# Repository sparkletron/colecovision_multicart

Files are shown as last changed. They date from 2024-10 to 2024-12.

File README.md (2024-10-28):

# Colecovision Multicart
## 15 in 1 flash ROM cart for Colecovision 32KiB ROMS.



author: Jay Convertino  

date: 2024.10.26

license: MIT

## Release Versions
### Current

  - pre-alpha

### Past

  - none
  
## Requirements

  - KiCad v7.X
  - xc8 v2.31 or greater
  - sdcc v4.0.0 or greater
  - make (build-essential)

  Tested on Ubuntu 22.04

## Brief Information

  Be sure to pull ALL submodules. The command for this is...

  ```console
  git submodule update --init --recursive
  ```

  This project creates a complete 15 in 1 multicart for the Colecovision. It will generate the needed ROM
  image, and firmware. Provides all the files needed for PCB creation, and the 3D printed case creation.

  No valid Colecovision ROMs are included in this project. Only valid ROM is the multicart application
  generated by RODAC. Game ROMs in RODAC are random data written in various bank sizes for testing only.

  Each folder in this root directory contains a part of the project, they are as follows.
  - docs, all documentation and detailed user manual.
  - schematic, Electrical schematic and gerbers from KiCAD.
  - src, all source files used to build the Multicart launcher and PIC support chip firmware.
  - models, STL files for printing out cart shell.

## Detailed Information

  For detailed usage information, please navigate to one of the following sources. They are the same, just in a different format.

  - [colecovision_multicart.pdf](docs/manual/colecovision_multicart.pdf)
  - [github wiki](https://github.com/sparkletron/colecovision_multicart/wiki)

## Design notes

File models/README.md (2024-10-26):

# Colecovision Multicart STL directory

author: Jay Convertino  

date: 2024.10.26

license: MIT

## Requirements
  - STL 3D printer application, CURA, simplify, etc.

  Tested on with a ABS on a D6 printer.

## Tips
  - Print using ABS at 100.5% sizing for both (ABS shrinks, alter this for your brand if needed).

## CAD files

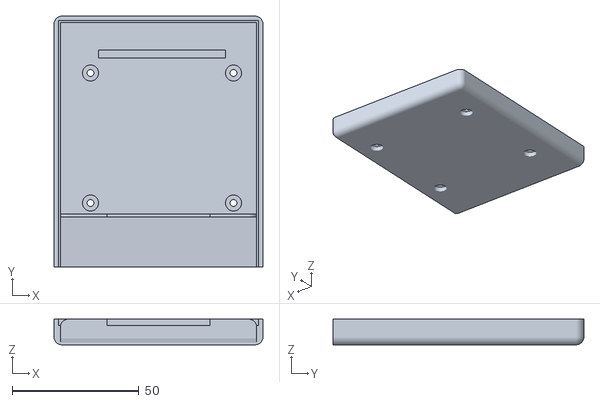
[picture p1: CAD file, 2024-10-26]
models/bottom.stl
82.6 x 99.1 x 10.2

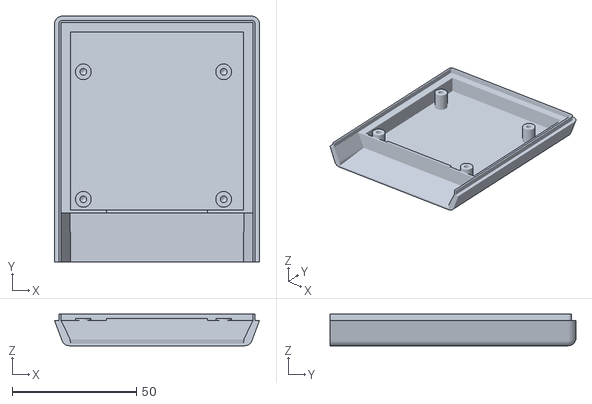
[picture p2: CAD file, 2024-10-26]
models/top.stl
82.6 x 99.1 x 12.7

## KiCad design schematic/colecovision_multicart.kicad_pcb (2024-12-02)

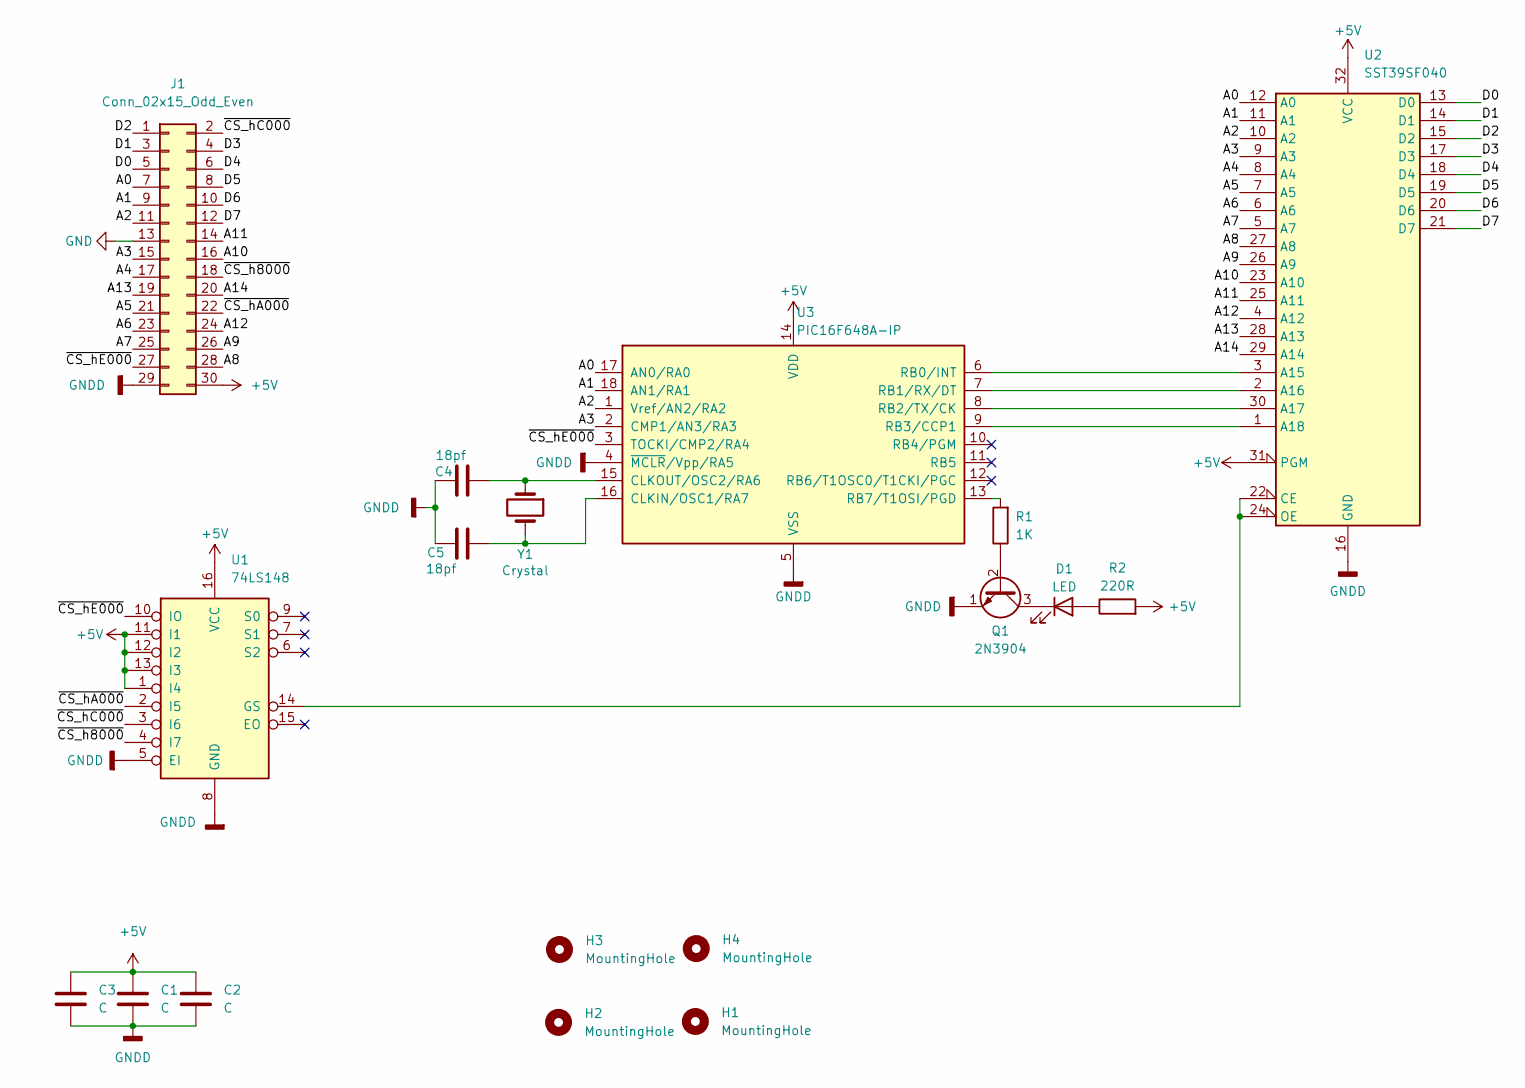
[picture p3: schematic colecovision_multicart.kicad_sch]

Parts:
C1, C2, C3: C; C_Disc_D5.0mm_W2.5mm_P5.00mm
C4, C5: 18pf; C_Disc_D3.0mm_W1.6mm_P2.50mm
D1: LED; LED_D3.0mm
H1, H2, H3, H4: MountingHole; MountingHole_3.2mm_M3_Pad
J1: Conn_02x15_Odd_Even; Colecovision_Cartridge
Q1: 2N3904; TO-92_Wide
R1: 1K; R_Axial_DIN0207_L6.3mm_D2.5mm_P7.62mm_Horizontal
R2: 220R; R_Axial_DIN0207_L6.3mm_D2.5mm_P7.62mm_Horizontal
U1: 74LS148; DIP-16_W7.62mm
U2: SST39SF040; DIP-32_W15.24mm
U3: PIC16F648A-IP; DIP-18_W7.62mm
Y1: Crystal; Crystal_HC49-4H_Vertical

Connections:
+5V: C1.1, C2.1, C3.1, J1.30, R2.2, U1.1 (I4), U1.11 (I1), U1.12 (I2), U1.13 (I3), U1.16 (VCC), U2.31 (PGM), U2.32 (VCC), U3.14 (VDD)
/A0: J1.7, U2.12 (A0), U3.17 (AN0/RA0)
/A1: J1.9, U2.11 (A1), U3.18 (AN1/RA1)
/A2: J1.11, U2.10 (A2), U3.1 (Vref/AN2/RA2)
/A3: J1.15, U2.9 (A3), U3.2 (CMP1/AN3/RA3)
/A4: J1.17, U2.8 (A4)
/A5: J1.21, U2.7 (A5)
/A6: J1.23, U2.6 (A6)
/A7: J1.25, U2.5 (A7)
/A8: J1.28, U2.27 (A8)
/A9: J1.26, U2.26 (A9)
/A10: J1.16, U2.23 (A10)
/A11: J1.14, U2.25 (A11)
/A12: J1.24, U2.4 (A12)
/A13: J1.19, U2.28 (A13)
/A14: J1.20, U2.29 (A14)
/D0: J1.5, U2.13 (D0)
/D1: J1.3, U2.14 (D1)
/D2: J1.1, U2.15 (D2)
/D3: J1.4, U2.17 (D3)
/D4: J1.6, U2.18 (D4)
/D5: J1.8, U2.19 (D5)
/D6: J1.10, U2.20 (D6)
/D7: J1.12, U2.21 (D7)
/~CS_h8000: J1.18, U1.4 (I7)
/~CS_hA000: J1.22, U1.2 (I5)
/~CS_hC000: J1.2, U1.3 (I6)
/~CS_hE000: J1.27, U1.10 (IO), U3.3 (TOCKI/CMP2/RA4)
GND: J1.13
GNDD: C1.2, C2.2, C3.2, C4.1, C5.2, J1.29, Q1.1 (E), U1.5 (EI), U1.8 (GND), U2.16 (GND), U3.4 (~MCLR/Vpp/RA5), U3.5 (VSS)
unnamed: D1.2 (A), R2.1
unnamed: D1.1 (K), Q1.3 (C)
unnamed: Q1.2 (B), R1.1
unnamed: U1.14 (GS), U2.22 (CE), U2.24 (OE)
unnamed: U2.3 (A15), U3.6 (RB0/INT)
unnamed: U2.2 (A16), U3.7 (RB1/RX/DT)
unnamed: U2.30 (A17), U3.8 (RB2/TX/CK)
unnamed: U2.1 (A18), U3.9 (RB3/CCP1)
unnamed: C5.1, U3.16 (CLKIN/OSC1/RA7), Y1.2
unnamed: C4.2, U3.15 (CLKOUT/OSC2/RA6), Y1.1
unnamed: R1.2, U3.13 (RB7/T1OSI/PGD)

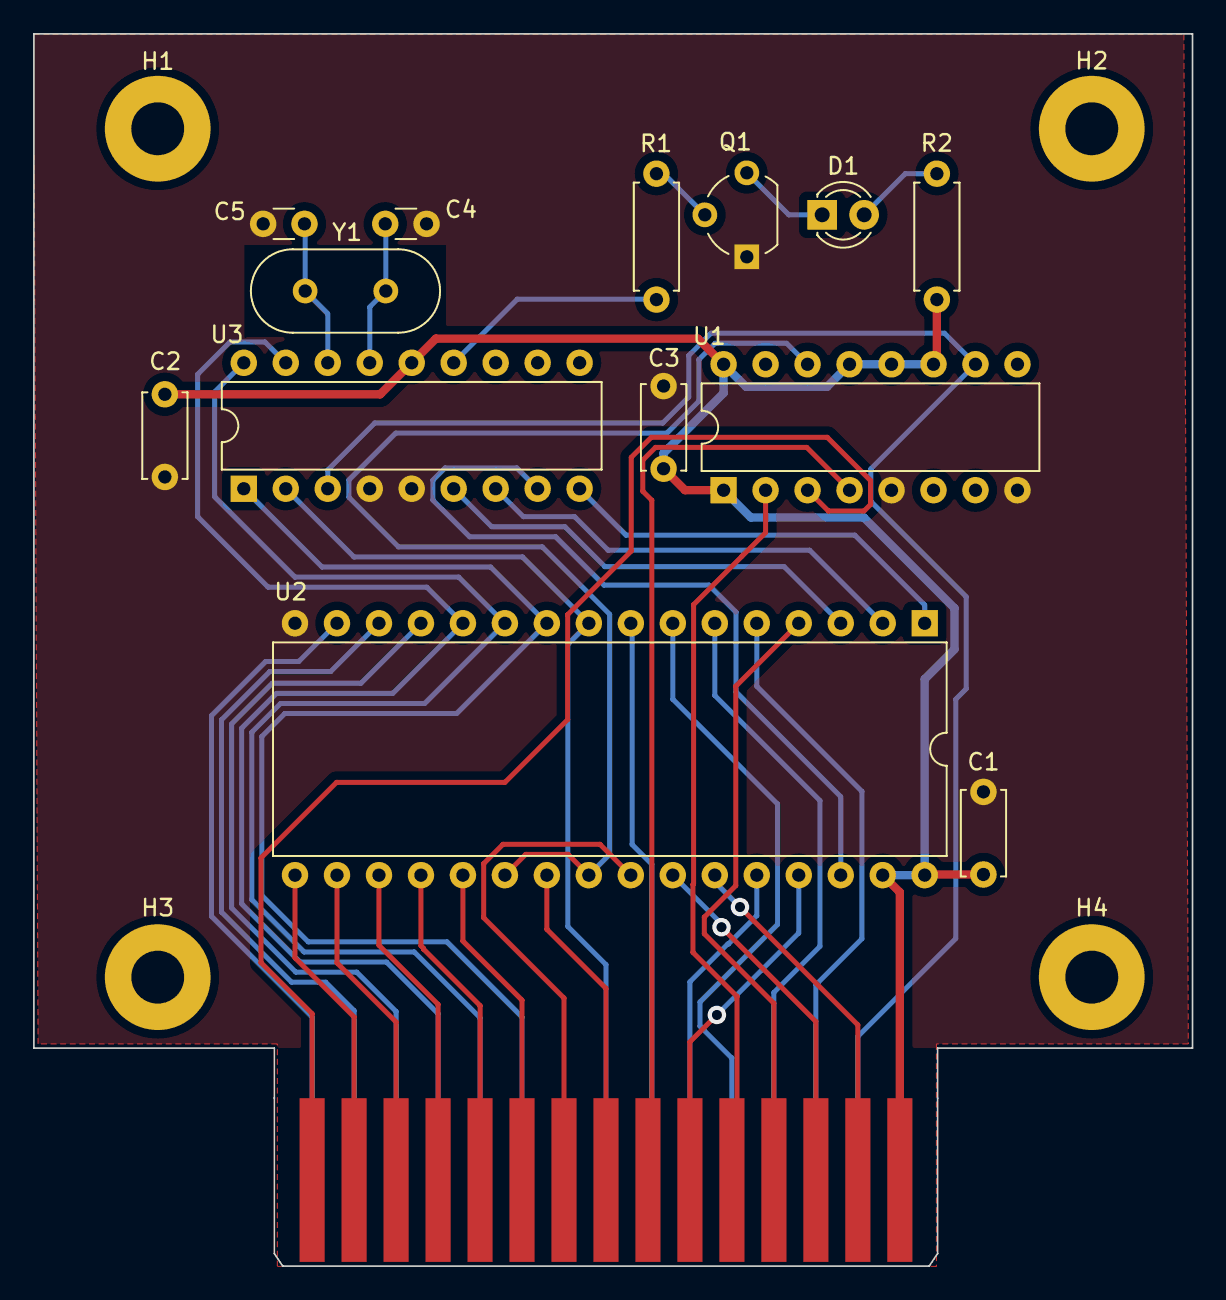
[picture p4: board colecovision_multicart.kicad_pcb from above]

Board: 2 copper layers, 70.1 x 74.6 mm, 18 parts (0 on the bottom side), 40 nets.

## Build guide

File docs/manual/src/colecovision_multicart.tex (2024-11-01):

\documentclass{article}
\usepackage{graphicx}
\usepackage{titling}
\usepackage{lmodern}
\usepackage{amsmath}
\usepackage{xcolor}
\usepackage{listings}
\lstset{
  breaklines=true,
  postbreak=\mbox{\textcolor{red}{$\hookrightarrow$}\space},
}
\usepackage{titlesec}
\usepackage{dirtree}
\usepackage{indentfirst}
\usepackage[hidelinks]{hyperref}
\title{{\Huge Colecovision Multicart Manual}}
\author{\Large Jay Convertino}
\date{\today}

\lstdefinelanguage
   [xc8]{Assembler}
   [x86masm]{Assembler}
   {morekeywords={bcf, movf, addlw, btfsc, goto, movwf}}

\begin{document}
  \begin{titlepage}
    \begin{center}

    \thetitle

    \vspace{25mm}

    

    \vspace{25mm}

    \thedate

    \vspace{15mm}

    \theauthor

    \end{center}
  \end{titlepage}

  \tableofcontents

  \newpage

  \section{Usage}

  \subsection{Introduction}

  \par
  This manual describes how to use the Multicart project and its architecture. This cart was designed to be cheap, and easy to use.
  By using a very basic microcontroller, and some inline assembly, a reliable multicart has been created. This cart allows you to
  select between 15 different ROMs. These 15 ROMs can be any Colecovision, or Colecovision Super Game Module game you wish. Only
  caveat is it has to be 32 KiB or less. This cart does not support MEGA ROMs.

  \subsection{Dependencies}

  \par
  Tested with Ubuntu 22.04

  \begin{itemize}
    \item KiCAD v7.X
    \item xc8 v2.31 or greater
    \item sdcc v4.0.0 or greater
    \item make (build-essential)
  \end{itemize}

  \subsection{Production File Location}

  \par
  These files will only exist once a build is completed (excluding Gerbers and STL files).

  \begin{itemize}
    \item \textbf{Gerbers} schematic/gerber/colecovision\_multicart.zip
    \item \textbf{PIC firmware} src/pic\_coleco\_addr\_sel/exe/colecoMultiCart.hex
    \item \textbf{ROM File} src/RODAC/apps/multicart/complete\_coleco\_multicart.bin
    \item \textbf{STL Bottom} models/bottom.stl
    \item \textbf{STL Top} models/top.stl
  \end{itemize}

  \subsection{Building}

  \paragraph{Parts List} \label{Parts}

  \par
  \begin{itemize}
    \item 1 pic16f648a
    \item 1 74HC148
    \item 1 SST39SF040
    \item 3 100nF 10v or greater ceramic capacitor
    \item 1 bottom case
    \item 1 top case
    \item 1 double sided PCB
    \item 4 \#4-24 x 1/2 inch Philips screws (FASTENAL 31206)
  \end{itemize}

  \par
  \paragraph{The Easy Way, Step By Step}

  \begin{itemize}
    \item \textbf{Order your parts, see {\ref{Parts}}}
    \item \textbf{PCB}
      \begin{enumerate}
        \item Send the file schematic/gerber/colecovision\_multicart.zip to your prefered fab.
        \item Standard board of 1.6mm thick with 1oz copper, double sided is fine.
        \item Wait
      \end{enumerate}
    \item \textbf{Build the ROM, and PIC Firmware}
      \begin{enumerate}
        \item Install sdcc v4.0.0 or greater.
        \item Install make
        \item Install xc8-cc
        \item Install MPLAB IPE
        \item Add up to 15 32 or less KiB ROMS to the src/roms folder. They must end in *.col.
        \item While in the src folder, run the following command to build the PIC firmware and multicart ROM.
        {\begin{lstlisting}[language=bash]
          $ make
        \end{lstlisting}}
        \item Program your PIC with a PICKIT or other programmer. FILE: src/pic\_coleco\_addr\_sel/exe/colecoMultiCart.hex
        \item Program the FLASH IC. FILE: src/RODAC/apps/multicart/complete\_coleco\_multicart.bin
      \end{enumerate}
    \item \textbf{3D printed Case}
      \begin{enumerate}
        \item Import STL files into your slicer of choice, or send out for printing. Files are located in the models folder and are called bottom.stl and top.stl.
        \item Note: I prefer ABS, but PLA should be fine.
        \item Slice and Print or wait for it in the mail.
      \end{enumerate}
    \item \textbf{Assembly}
      \begin{enumerate}
        \item All parts are through hole, soldering these can be done with most irons.
        \item Populate the PCB with the preprogrammed IC parts.
        \item Add the last IC 74HC148
        \item Solder all of the caps to the PCB
        \item Ignore the extra holes, they are for an LED indicator that indicates the bank switch has been set. It does work, just didn't make a hole in the shell for it.
        \item Place the PCB with the ICs facing up towards the top shell in the bottom shell of the cart. It is the bottom.stl file.
        \item Place the top of the shell on the bottom shell. It may need some tweaking, but it will fit.
        \item Insert the 4 screws into the back.
        \item Place the cart on a hard flat surface, and tighten the screws till the shell is closed.
        \item Add a label (avery 5816 is a good choice).
      \end{enumerate}
    \item \textbf{Enjoy your new cart!}
  \end{itemize}

  \subsubsection{Colecovision ROM}

  \par
  The build system used for the Colecovision is called RODAC (Retro Only Device Application Creation). This is a pre-alpha state set of C libraries that use sdcc.
  The difference between this build system and others is the goal of targeting multiple systems with base libraries and very few ifdefs for switching out code.
  All paths given below are from the src/RODAC parent directory.
  \par
  RODAC uses a makefile based build system. The all target will build nothing in any of the apps. The makefile to build the apps is located in each app. For instance
  the HELLO\_WORLD application is located at apps/hello\_world. To execute the build you would simply navigate to apps/hello\_world, and run the make command with
  your target system. Example for the Colecovision would be

  \begin{lstlisting}[language=bash]
    $ make coleco
  \end{lstlisting}

  The Colecovision with a super game module would be

  \begin{lstlisting}[language=bash]
    $ make coleco_sgm
  \end{lstlisting}

  \par
  The app of interest for this project is multicart, located at apps/multicart. Details about the code can be seen at \ref{Colecovision Multicart} . For now all we care about is building
  the code. Building is automated with a makefile that calls two python scripts. rom\_header\_gen.py, which alters the roms.h header string array with the names of the ROMs
  given to it. rom\_file\_gen.py is executed at the end and takes all of the ROM files, including the multicart program and generates the flash ROM image. This currently
  defaults to 15 ROMs + Multicart for a total of 512 KiB. Each ROM is padded if it is less then 32 KiB.

  \paragraph{Burning ROM}
  To burn the ROM you will need to use the file complete\_coleco\_multicart.bin. This will be located in src/RODAC/apps/multicart. Any programmer compatible with the
  SST39SF040 will work without issue. For the minipro with a TL866A the example command is

  \begin{lstlisting}[language=bash]
$ minipro -p SST39SF040 -w complete_coleco_multicart.bin
  \end{lstlisting}

  \subsubsection{Microcontroller Code}

  \par
  PIC16F648A is the target microcontroller. Building the code is handled by a makefile that calls xc8-cc. Currently using versions 2.31, but anything greater than that should work
  fine, but has not been tested. Simply navigate to src/pic\_coleco\_addr\_sel and run

  \begin{lstlisting}[language=bash]
    $ make
  \end{lstlisting}

  If xc8-cc is installed and available in the the PATH the build will execute. The resulting
  outputs are in the exe folder located in the same location. In the exe folder the output needed is colecoMultiCart.hex .

  \paragraph{Program PIC}
  Easiest way without installing all of MPLAB is to install MPLAB IPE only. This tool will allow you to use a PICKIT programmer with your PC and upload code to controller.
  The flash cart board does not have a header for programming the PIC. Easiest way is to wire it up a breadboard with the chip and upload the code with a PICKIT and MPLAB IPE.
  The full file you will need is src/pic\_coleco\_addr\_sel/exe/colecoMultiCart.hex.

  \subsubsection{PCB}

  \par
  PCB design was created with KiCAD version 7.X. This is a double sided PCB for the Colecovision only. The
  design contains three vias for a few traces that needed to switch sides. Exported gerbers are located at
  schematic/gerber/. This also contains a zip file for production use. Standard settings for any PCB house
  will be fine.

  \subsubsection{3D printed Case}

  \par
  There are two STL files for 3D printing a cartridge case. The file bottom.stl is the bottom, and top.stl is the top.
  These files have been printed with ABS at 100.5 percent. The extra half I find offsets any shrinkage in the ABS I own.
  PLA and such should not need this 0.5 percent increase in size. The case requires 4 screws. I used \#4-24 x 1/2 inch
  Philips screws from Fastenal, part number 31206.

  \subsection{Directory Guide}

  \dirtree{%
    .1 docs/.
    .2 datasheets.
    .2 manual.
    .1 schematic/.
    .2 gerber.
    .2 step.
    .1 src/.
    .2 pic\_coleco\_addr\_sel.
    .2 firmware.
    .1 model/.
  }

  \vspace{\baselineskip}

  \par
  The listing shows the important directories for this project. Below describes each section.

  \begin{enumerate}
    \item \textbf{docs} Contains all documentation related to this project.
      \begin{itemize}
        \item \textbf{datasheets} Contains all IC datasheets used for the hardware.
        \item \textbf{manual} Contains user manual and wiki that are generated from the same latex source.
      \end{itemize}
    \item \textbf{schematic} Contains KiCAD schematic for the project, currently version 7.x of KiCAD.
      \begin{itemize}
        \item \textbf{gerber} Export of schematic gerbers are placed here.
        \item \textbf{step} Export of 3D step model here for case fitment.
      \end{itemize}
    \item \textbf{src} Contains all source code related to the project.
      \begin{itemize}
        \item \textbf{pic\_coleco\_addr\_sel} pic16 source code and build system, uses xc8 compiler. Any version over 2.X should work fine.
        \item \textbf{RODAC} Colecovision development kit that uses SDCC. The multicart app will generate the project and build rom file.
      \end{itemize}
    \item \textbf{models} Contains all STL models for cartridge case.
  \end{enumerate}

  \newpage

  \section{Architecture}
  \subsubsection{General Description}

  \par
  The overall architecture is fairly simple and has the following steps.

  \begin{enumerate}
    \item Boot Colecovision in standard banner mode. Display multicart title.
    \item Display selection screen in TMS text mode.
    \item Highlight current user selection, defaulting at the 1st entry.
    \item Allow user to scroll through list, Highlight the user selected entry.
    \item Once fire is pressed, the highlighted entry is selected for bank switching.
    \item Colecovision code will load a new banner telling the user to reset the console.
    \item Colecovision will spam the address E001 + entry(0 to 14) 4 times to activate PIC.
    \item When E000n enable line goes low and the PIC catches it, the PIC will then set its ROM output address lines to the Coleco input address lines.
    \item User will reset console, console will now read the bank switched ROM from multicart.
  \end{enumerate}

  \subsubsection{Excuses} \label{Excuses}

  \par
  One of the major items you may notice is the need for the user to reset the console. This is due to my design, being a pain to time correctly.
  By making the user reset the console, which is much slower than the console, the Colecovision and the PIC can be synced easily. Yes that PIC is the reason for this.
  The PIC at 20 MHz takes 200ns to execute each instruction. Currently my algorithm (see \ref{PIC address selection}) will take 1000ns to sample, test the sample and then
  decide if E000n is active. The E000n pulse was measured to only be 620ns. Since the PIC is simply in a loop sampling, this means the pulse can be missed by the
  microcontroller. Easy way to fix this is to spam a few reads, in this case four, from the Colecovision Multicart program.
  \par
  Now the PIC has to set the address. This of course is fairly quick, sometimes too quick and results in corruption. Mostly with Atari games. This resulted in the idea
  of using a halt instead of reset. Basically the Colecovision code spams the read four times, then goes to a halt. The PIC picks up the read, captures the address and
  then waits for 1 second. After than second it bank switches the ROM. Since the console is halted this presents no issue and the user can now reset the console to
  start their game.
  \par
  Getting the timing between the two perfect could be achieved, heck others have done it. Frankly, this was the easy way out for now. Maybe in the future I'll revisit the issue.
  Though the goal is small and cheap. Three IC's is fairly small for the multicart, and as it is now works perfectly for my usecase.

  \newpage

  \section{Code Highlights}

  \par
  This section is parts of the code I think are interesting or could use just a bit more information about the files.

  \subsection{PIC address selection} \label{PIC address selection}

  \par
  Using a PIC causes some issues listed in the \ref{Excuses} subsection. The xc8-cc compiler will add bank switching to every porta/b read even if
  it is already at the correct bank. This adds 400ns of overhead at a 20 MHz clock. Using inline assembly I was able to read a port and check it again
  in 1000ns. Still not perfect, but better than the C generated code. The resulting code is below.

  \begin{lstlisting}[language={[xc8]Assembler}]

  bcf STATUS, 5
  bcf STATUS, 6
  test:
  movf  PORTA,w
  addlw 0xF0
  btfsc STATUS,0
  goto test
  movwf 0x20
  \end{lstlisting}

  \par
  The bcf STATUS clears the bank select bits to 0 before the loop that constantly reads the port. xc8 would put this in the loop.
  The input address pins and the E000n enable are on the same port. This is done by design. Since if its 0, we know that the Coleco input address bits
  contained in the work register are valid. If we do a read after, we run the risk of missing the bits since we are polling the port.
  By polling the port we don't know if we are close to the leading edge or trailing edge of the pulse. If we are at the end we will miss the
  address since the next read to the port will be too late. The read from PORTA will always be b000XXXXX (X is unknown). The top 2 bits
  are always 0 by design per the PIC16F648a manual when using a crystal oscillator. Bit 5 is 0 since it is tied to ground. The rest are sampled
  from the inputs tied to them. Bit 4 is the E000n select line. Bits 3 to 0 are address lines 3 to 0 from the Colecovision. The reason bit 4 is
  the select line is if its high, 1, and a add of b11110000 (0xF0) is executed this will overflow. Then the instruction brfsc tests the STATUS bit.
  If it is 1, an overflow occured and we continue the loop. If the bit is clear, we skip the next instruction, in this case the goto test that creates the loop.
  Once we exit the loop and move the work register contents to general register h20. This is is so we don't destroy the address value read earlier.

  \par
  Next the code will delay for about one second. This is so the Colecovision can reach the HALT state before the new address value for the
  bank switch is applied. If this happened before the HALT the code would switch to the new bank causing issues, as it would start executing
  the new code. The rest of the code simply pulls the contents of general register h20 back to the work register and writes it to PORTB. This write
  is the bank select based on the address read. Then the PIC loops forever doing nothing.

  \subsection{Colecovision Multicart} \label{Colecovision Multicart}

  \par
  Multicart application is written in C and uses the RODAC development environment. This is a pre-alpha set of libraries targeting retro hardware.
  This code was fairly easy and doesn't have many oddities. This section will highlight interesting bits.

  \par
  The only library used is the TMS99XX. This was originally written for testing TMS based chips on a PIC mircocontroller. It worked well and has been
  ported to SDCC. This port needs polish, but does work well enough for the multicart application. This application does not use the NMI as its such
  a slow update rate for user input. The TMS is put into TXT mode since it allows for 40 columns, and no sprites are needed for a simple menu.
  Highlighting is done by writing a inverted character set to the pattern table of the TMS RAM. An example of this code is below.

  \begin{lstlisting}[language=C]

/* invert ascii chars */
for(int inv_index = 0; inv_index < sizeof(c_tms99XX_ascii); inv_index++)
{
  /**** write data to port from array of data at index ****/
  VDP_DATA_PORT = ~(((uint8_t *)c_tms99XX_ascii)[inv_index]);
}
  \end{lstlisting}

  \par
  The index variable tracks the current selection of the ROM. This is from zero to fourteen. Once interesting bug I found was using mod 15 to do the wrap did
  not work well. It would sometimes go past in the emulator. Changed this to a ternary operator that does a comparison. This works for both going
  less than zero or greater than 14. The number of items allowed to be indexed is dictated by the length of the string array.
  This allows the multicart program to support any size up to the number of rows available. Scrolling has not been added. Maybe in the future.
  \par
  The controller read is done in a way to make it quick when the button is held, but also work when quickly pressed by the user. A buffer filters the input
  presses of the user, and is simply shifted until it is 0. Then there is timeout counter that if nothing is pressed, the buffer is reset to its default value
  of all ones. There is also a delay at the end of the loop to take a pause between screen updates. An example of this code is below.

  \begin{lstlisting}[language=C]

if(!((controller >> FIRE_BIT) & 0x01))
{
  //do we care?
}
else if(!((controller >> UP_BIT) & 0x01))
{
  buffer = buffer << 1;

  if(!buffer)
  {
    index = (index > 0 ? (index - 1) : num_of_roms-1);

    buffer = (uint8_t)~0;
  }
}
/* when down is pressed, and its 0 shift a buffer till its 0, then increment index to move the highlight down the screen */
else if(!((controller >> DOWN_BIT) & 0x01))
{
  buffer = buffer << 1;

  if(!buffer)
  {
    index = (index < num_of_roms-1 ? (index + 1) : 0);

    buffer = (uint8_t)~0;
  }
}
/* nothing? then do a count to allow quick presses to shift the buffer, and if its been to long, clear everything out */
else
{
  counter += 1;

  if(counter > 32)
  {
    counter = 0;
    buffer = (uint8_t)~0;
  }
}

  \end{lstlisting}

  \par
  As for the reading E001 + index four times. This is dues to the PIC is explained in \ref{Excuses}. Example of the code below.

  \begin{lstlisting}[language=C]

buffer = *(bank_switch + index);
buffer = *(bank_switch + index);
buffer = *(bank_switch + index);
buffer = *(bank_switch + index);
  \end{lstlisting}

\end{document}

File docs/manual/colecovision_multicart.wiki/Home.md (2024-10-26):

---
author:
- Jay Convertino
title: Colecovision Multicart Manual
---

{width="\\textwidth"
height="\\textheight"}

Usage
=====

Introduction
------------

This manual describes how to use the Multicart project and its
architecture. This cart was design to be cheap, and easy to use. By
using a very basic microcontroller and some inline assembly a reliable
multicart has been created. This cart allows you to select between 15
different ROMS. These 15 ROMS can be any colecovision, or colecovision
Super Game Module game you wish. Only caveat is it has to be 32 KiB or
less. This cart does not support MEGA roms.

Dependecies
-----------

COMING SOON(TM)

Building
--------

COMING SOON(TM)

### Colecovision ROM

COMING SOON(TM)

### Microcontroller Code

COMING SOON(TM)

### PCB

COMING SOON(TM)

### 3D printed Case

COMING SOON(TM)

Directory Guide
---------------

The above listing shows the important directories for this project. The
list below describes each section.

1.  **docs** Contains all documentation related to this project.

    -   **datasheets** Contains all IC datasheets used for the hardware.

    -   **manual** Contains user manual and wiki that are generated from
        the same latex source.

2.  **schematic** Contains KiCAD schematic for the project, currently
    version 7.x of KiCAD.

    -   **gerber** Export of schematic gerbers are placed here.

    -   **step** Export of 3D step model here for case fitment.

3.  **src** Contains all source code related to the project.

    -   **pic\_coleco\_addr\_sel** pic16 source code and build system,
        uses xc8 compiler. Any version over 2.X should work fine.

    -   **firmware** Colecovision development kit that uses SDCC. The
        multicart app will generate the project and build rom file.

Architecture
============

### General Desciption

The overall architecture is fairly simple and has the following steps.

1.  Boot colecovision in standard banner mode. Display multicart title.

2.  Display selection screen in TMS text mode.

3.  Highlight current user selection, defaulting at the 1st entry.

4.  Once fire is pressed, the highlighted entry is selected for bank
    switching.

5.  Colecovision code will load a new banner telling the user to reset
    the console.

6.  Colecovision will spam the address E001 + entry(0 to 14) 4 times to
    activate PIC.

7.  When E000n enable line goes low and the PIC catches it, the PIC will
    then set its output address lines to the rom to the input address
    lines.

8.  User will reset console, console will now read the bank switched ROM
    from multicart.

### Excuses

One of the major items you may notice is the need for the user to reset
the console. This is due to my design, being a pain to time correctly.
By making the user reset the console, which is much slower than the
console, the colecovision and the PIC can be synced easily. Yes that PIC
is the reason for this. The PIC at 20 MHz takes 200ns to execute each
instruction. Currently my algorithm (see
[3.1](#PIC address selection){reference-type="ref"
reference="PIC address selection"}) will take 1000ns to sample, test the
sample and then decide if E000n is active. The E000n pulse was measured
to only be 620ns. Since the PIC is simply in a loop sampling, this means
the pulse can be missed by the microcontroller. Easy way to fix this is
to spam a few reads, in this case four, from the Colecovision Multicart
program.

Now the PIC has to set the address. This of course is fairly quick,
sometimes too quick and results in corruption. Mostly with Atari games.
This resulted in the idea of using a halt instead of reset. Basically
the Colecovision code spams the read four times, then goes to a halt.
The PIC picks up the read, captures the address and then waits for 1
second. After than second it bank switches the ROM. Since the console is
halted this presents no issue and the user can now reset the console to
start their game.

Getting the timing between the two perfect could be achieved, heck
others have done it. Frankly, this was the easy way out for now. Maybe
in the future I'll revisit it. Though the goal is small and cheap. Three
IC's is fairly small for the multicart, and as it is now works perfectly
for my usecase.

Code Highlights
===============

PIC address selection {#PIC address selection}
---------------------

Colecovision Multicart
----------------------

Python Generators
-----------------

### ROM Header Generator

### ROM File Generator

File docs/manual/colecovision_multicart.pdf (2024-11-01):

# Colecovision Multicart Manual

October 31, 2024

## Jay Convertino

## Contents

1 Usage | 2
2 Architecture | 7
3 Code Highlights | 8

1

## 1 Usage

### 1.1 Introduction

This manual describes how to use the Multicart project and its architecture. This cart was designed to be cheap, and easy to use. By using a very basic microcontroller, and some inline assembly, a reliable multicart has been created. This cart allows you to select between 15 different ROMs. These 15 ROMs can be any Colecovision, or Colecovision Super Game Module game you wish. Only caveat is it has to be 32 KiB or less. This cart does not support MEGA ROMs.

### 1.2 Dependencies

Tested with Ubuntu 22.04

- KiCAD v7.X
- xc8 v2.31 or greater
- sdcc v4.0.0 or greater
- make (build-essential)

### 1.3 Production File Location

These files will only exist once a build is completed (excluding Gerbers and STL files).

- Gerbers schematic/gerber/colecovision multicart.zip
- PIC firmware src/pic coleco addr sel/exe/colecoMultiCart.hex
- ROM File src/RODAC/apps/multicart/complete coleco multicart.bin
- STL Bottom models/bottom.stl
- STL Top models/top.stl

### 1.4 Building

Parts List

- 1 pic16f648a
- 1 74HC148
- 1 SST39SF040
- 3 100nF 10v or greater ceramic capacitor
- 1 bottom case

2

- 1 top case
- 1 double sided PCB
- 4 #4-24 x 1/2 inch Philips screws (FASTENAL 31206)

The Easy Way, Step By Step

- Order your parts, see 1.4
- PCB
1. Send the file schematic/gerber/colecovision multicart.zip to your prefered fab.
2. Standard board of 1.6mm thick with 1oz copper, double sided is fine.
3. Wait
- Build the ROM, and PIC Firmware
1. Install sdcc v4.0.0 or greater.
2. Install make
3. Install xc8-cc
4. Install MPLAB IPE
5. Add up to 15 32 or less KiB ROMS to the src/roms folder. They must end in *.col.
6. While in the src folder, run the following command to build the PIC firmware and multicart ROM.

$ make

7. Program your PIC with a PICKIT or other programmer. FILE: src/pic coleco addr sel/exe/colecoMultiCart.hex
8. Program the FLASH IC. FILE: src/RODAC/apps/multicart/complete coleco multicart.bin
- 3D printed Case
1. Import STL files into your slicer of choice, or send out for printing. Files are located in the models folder and are called bottom.stl and top.stl.
2. Note: I prefer ABS, but PLA should be fine.
3. Slice and Print or wait for it in the mail.
- Assembly
1. All parts are through hole, soldering these can be done with most irons.

3

2. Populate the PCB with the preprogrammed IC parts.
3. Add the last IC 74HC148
4. Solder all of the caps to the PCB
5. Ignore the extra holes, they are for an LED indicator that indicates the bank switch has been set. It does work, just didn’t make a hole in the shell for it.
6. Place the PCB with the ICs facing up towards the top shell in the bottom shell of the cart. It is the bottom.stl file.
7. Place the top of the shell on the bottom shell. It may need some tweaking, but it will fit.
8. Insert the 4 screws into the back.
9. Place the cart on a hard flat surface, and tighten the screws till the shell is closed.
10. Add a label (avery 5816 is a good choice).
- Enjoy your new cart!

### 1.4.1 Colecovision ROM

The build system used for the Colecovision is called RODAC (Retro Only Device Application Creation). This is a pre-alpha state set of C libraries that use sdcc. The difference between this build system and others is the goal of targeting multiple systems with base libraries and very few ifdefs for switching out code. All paths given below are from the src/RODAC parent directory. RODAC uses a makefile based build system. The all target will build nothing in any of the apps. The makefile to build the apps is located in each app. For instance the HELLO WORLD application is located at apps/hello world. To execute the build you would simply navigate to apps/hello world, and run the make command with your target system. Example for the Colecovision would be

$ make c o l e c o

The Colecovision with a super game module would be

$ make c ol e c o s gm

The app of interest for this project is multicart, located at apps/multicart. Details about the code can be seen at 3.2 . For now all we care about is building the code. Building is automated with a makefile that calls two python scripts. rom header gen.py, which alters the roms.h header string array with the names of the ROMs given to it. rom file gen.py is executed at the end and takes all of the ROM files, including the multicart program and generates the flash ROM image. This currently defaults to 15 ROMs + Multicart for a total of 512 KiB. Each ROM is padded if it is less then 32 KiB.

4

Burning ROM To burn the ROM you will need to use the file complete coleco multicart.bin. This will be located in src/RODAC/apps/multicart. Any programmer compatible with the SST39SF040 will work without issue. For the minipro with a
TL866A the example command is

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

### 1.4.2 Microcontroller Code

PIC16F648A is the target microcontroller. Building the code is handled by a makefile that calls xc8-cc. Currently using versions 2.31, but anything greater than that should work fine, but has not been tested. Simply navigate to src/pic coleco addr sel and run

$ make

If xc8-cc is installed and available in the the PATH the build will execute. The resulting outputs are in the exe folder located in the same location. In the exe folder the output needed is colecoMultiCart.hex .

Program PIC Easiest way without installing all of MPLAB is to install MPLAB IPE only. This tool will allow you to use a PICKIT programmer with your PC and upload code to controller. The flash cart board does not have a header for programming the PIC. Easiest way is to wire it up a breadboard with the chip and upload the code with a PICKIT and MPLAB IPE. The full file you will need is src/pic coleco addr sel/exe/colecoMultiCart.hex.

### 1.4.3 PCB

PCB design was created with KiCAD version 7.X. This is a double sided PCB for the Colecovision only. The design contains three vias for a few traces that needed to switch sides. Exported gerbers are located at schematic/gerber/. This also contains a zip file for production use. Standard settings for any PCB house will be fine.

1.4.4 3D printed Case

There are two STL files for 3D printing a cartridge case. The file bottom.stl is the bottom, and top.stl is the top. These files have been printed with ABS at 100.5 percent. The extra half I find offsets any shrinkage in the ABS I own. PLA and such should not need this 0.5 percent increase in size. The case requires 4 screws. I used #4-24 x 1/2 inch Philips screws from Fastenal, part number 31206.

### 1.5 Directory Guide

docs/

5

datasheets
manual
schematic/
gerber
step
src/
pic coleco addr sel
firmware
model/

The listing shows the important directories for this project. Below describes each section.

1. docs Contains all documentation related to this project.
- datasheets Contains all IC datasheets used for the hardware.
- manual Contains user manual and wiki that are generated from the same latex source.
2. schematic Contains KiCAD schematic for the project, currently version 7.x of KiCAD.
- gerber Export of schematic gerbers are placed here.
- step Export of 3D step model here for case fitment.
3. src Contains all source code related to the project.
- pic coleco addr sel pic16 source code and build system, uses xc8 compiler. Any version over 2.X should work fine.
- RODAC Colecovision development kit that uses SDCC. The multicart app will generate the project and build rom file.
4. models Contains all STL models for cartridge case.

6

## 2 Architecture

### 2.0.1 General Description

The overall architecture is fairly simple and has the following steps.

1. Boot Colecovision in standard banner mode. Display multicart title.
2. Display selection screen in TMS text mode.
3. Highlight current user selection, defaulting at the 1st entry.
4. Allow user to scroll through list, Highlight the user selected entry.
5. Once fire is pressed, the highlighted entry is selected for bank switching.
6. Colecovision code will load a new banner telling the user to reset the console.
7. Colecovision will spam the address E001 + entry(0 to 14) 4 times to activate PIC.
8. When E000n enable line goes low and the PIC catches it, the PIC will then set its ROM output address lines to the Coleco input address lines.
9. User will reset console, console will now read the bank switched ROM from multicart.

### 2.0.2 Excuses

One of the major items you may notice is the need for the user to reset the console. This is due to my design, being a pain to time correctly. By making the user reset the console, which is much slower than the console, the Colecovision and the PIC can be synced easily. Yes that PIC is the reason for this. The PIC at 20 MHz takes 200ns to execute each instruction. Currently my algorithm (see 3.1) will take 1000ns to sample, test the sample and then decide if E000n is active. The E000n pulse was measured to only be 620ns. Since the PIC is simply in a loop sampling, this means the pulse can be missed by the microcontroller. Easy way to fix this is to spam a few reads, in this case four, from the Colecovision Multicart program.
Now the PIC has to set the address. This of course is fairly quick, sometimes too quick and results in corruption. Mostly with Atari games. This resulted in the idea of using a halt instead of reset. Basically the Colecovision code spams the read four times, then goes to a halt. The PIC picks up the read, captures the address and then waits for 1 second. After than second it bank switches the ROM. Since the console is halted this presents no issue and the user can now reset the console to start their game.
Getting the timing between the two perfect could be achieved, heck others have done it. Frankly, this was the easy way out for now. Maybe in the future I’ll revisit the issue. Though the goal is small and cheap. Three IC’s is fairly small for the multicart, and as it is now works perfectly for my usecase.

7

## 3 Code Highlights

This section is parts of the code I think are interesting or could use just a bit more information about the files.

### 3.1 PIC address selection

Using a PIC causes some issues listed in the 2.0.2 subsection. The xc8-cc compiler will add bank switching to every porta/b read even if it is already at the correct bank. This adds 400ns of overhead at a 20 MHz clock. Using inline assembly I was able to read a port and check it again in 1000ns. Still not perfect, but better than the C generated code. The resulting code is below.

bcf STATUS, 5
bcf STATUS, 6
test :
movf PORTA,w
addlw 0xF0
bt fsc STATUS, 0
goto test
movwf 0 x20

The bcf STATUS clears the bank select bits to 0 before the loop that constantly reads the port. xc8 would put this in the loop. The input address pins and the E000n enable are on the same port. This is done by design. Since if its 0, we know that the Coleco input address bits contained in the work register are valid. If we do a read after, we run the risk of missing the bits since we are polling the port. By polling the port we don’t know if we are close to the leading edge or trailing edge of the pulse. If we are at the end we will miss the address since the next read to the port will be too late. The read from PORTA will always be b000XXXXX (X is unknown). The top 2 bits are always 0 by design per the PIC16F648a manual when using a crystal oscillator. Bit 5 is 0 since it is tied to ground. The rest are sampled from the inputs tied to them. Bit 4 is the E000n select line. Bits 3 to 0 are address lines 3 to 0 from the Colecovision. The reason bit 4 is the select line is if its high, 1, and a add of b11110000 (0xF0) is executed this will overflow. Then the instruction brfsc tests the STATUS bit. If it is 1, an overflow occured and we continue the loop. If the bit is clear, we skip the next instruction, in this case the goto test that creates the loop. Once we exit the loop and move the work register contents to general register h20. This is is so we don’t destroy the address value read earlier.
Next the code will delay for about one second. This is so the Colecovision can reach the HALT state before the new address value for the bank switch is applied. If this happened before the HALT the code would switch to the new bank causing issues, as it would start executing the new code. The rest of the code simply pulls the contents of general register h20 back to the work register and writes it to PORTB. This write is the bank select based on the address

8

read. Then the PIC loops forever doing nothing.

### 3.2 Colecovision Multicart

Multicart application is written in C and uses the RODAC development environment. This is a pre-alpha set of libraries targeting retro hardware. This code was fairly easy and doesn’t have many oddities. This section will highlight interesting bits.
The only library used is the TMS99XX. This was originally written for testing TMS based chips on a PIC mircocontroller. It worked well and has been ported to SDCC. This port needs polish, but does work well enough for the multicart application. This application does not use the NMI as its such a slow update rate for user input. The TMS is put into TXT mode since it allows for 40 columns, and no sprites are needed for a simple menu. Highlighting is done by writing a inverted character set to the pattern table of the TMS RAM. An example of this code is below.

## /∗ i n v e r t a s c i i c h a r s ∗/

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

,→ ∗∗∗ ∗/
VDP DATA PORT = ˜ ( ( ( u i n t 8 t ∗) c tm s 9 9XX a s cii ) [
,→ i n v i n d e x ] ) ;
}

The index variable tracks the current selection of the ROM. This is from zero to fourteen. Once interesting bug I found was using mod 15 to do the wrap did not work well. It would sometimes go past in the emulator. Changed this to a ternary operator that does a comparison. This works for both going less than zero or greater than 14. The number of items allowed to be indexed is dictated by the length of the string array. This allows the multicart program to support any size up to the number of rows available. Scrolling has not been added. Maybe in the future.
The controller read is done in a way to make it quick when the button is held, but also work when quickly pressed by the user. A buffer filters the input presses of the user, and is simply shifted until it is 0. Then there is timeout counter that if nothing is pressed, the buffer is reset to its default value of all ones. There is also a delay at the end of the loop to take a pause between screen updates. An example of this code is below.

i f ( ! ( ( c o n t r o l l e r >> FIRE BIT ) & 0 x01 ) )
{

## // do we c a re ?

}

9

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

i f ( ! b u f f e r )
{
inde x = ( inde x > 0 ? ( inde x − 1 ) : num o f roms −1) ;

b u f f e r = ( u i n t 8 t ) ˜ 0;
}
}

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

i f ( ! b u f f e r )
{
inde x = ( inde x < num o f roms−1 ? ( inde x + 1 ) : 0 ) ;

b u f f e r = ( u i n t 8 t ) ˜ 0;
}
}

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

e l s e
{
c o u n t e r += 1 ;

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

As for the reading E001 + index four times. This is dues to the PIC is explained in 2.0.2. Example of the code below.

b u f f e r = ∗( b an k swi tch + inde x ) ;
b u f f e r = ∗( b an k swi tch + inde x ) ;
b u f f e r = ∗( b an k swi tch + inde x ) ; b u f f e r = ∗( b an k swi tch + inde x ) ;

10

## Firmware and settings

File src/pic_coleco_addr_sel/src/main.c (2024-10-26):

/*******************************************************************************
 * @file    main.c
 * @author  Jay Convertino(electrobs@gmail.com)
 * @date    2024.10.16
 * @brief   Coleco Multicart Selection PIC uC
 *
 * CONTROLLER: PIC16F648A
 *
 * @license mit
 *
 * Copyright 2024 Johnathan Convertino
 *
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
 * THE SOFTWARE IS PROVIDED "AS IS", WITHOUT WARRANTY OF ANY KIND, EXPRESS OR
 * IMPLIED, INCLUDING BUT NOT LIMITED TO THE WARRANTIES OF MERCHANTABILITY,
 * FITNESS FOR A PARTICULAR PURPOSE AND NONINFRINGEMENT. IN NO EVENT SHALL THE
 * AUTHORS OR COPYRIGHT HOLDERS BE LIABLE FOR ANY CLAIM, DAMAGES OR OTHER
 * LIABILITY, WHETHER IN AN ACTION OF CONTRACT, TORT OR OTHERWISE, ARISING
 * FROM, OUT OF OR IN CONNECTION WITH THE SOFTWARE OR THE USE OR OTHER DEALINGS
 * IN THE SOFTWARE.
 ******************************************************************************/

#include <xc.h>
#include <stdint.h>
#include <pic16f648a.h>

//setup to XTAL freq, for _delay macros
#define _XTAL_FREQ      20000000

// #pragma config statements should precede project file includes.
// Use project enums instead of #define for ON and OFF.

// CONFIG
#pragma config FOSC = HS        // Oscillator Selection bits (INTOSC oscillator: I/O function on RA6/OSC2/CLKOUT pin, I/O function on RA7/OSC1/CLKIN)
#pragma config WDTE = OFF       // Watchdog Timer Enable bit (WDT disabled)
#pragma config PWRTE = ON       // Power-up Timer Enable bit (PWRT enabled)
#pragma config MCLRE = OFF      // RA5/MCLR/VPP Pin Function Select bit (RA5/MCLR/VPP pin function is digital input, MCLR internally tied to VDD)
#pragma config BOREN = OFF      // Brown-out Detect Enable bit (BOD disabled)
#pragma config LVP = OFF        // Low-Voltage Programming Enable bit (RB4/PGM pin has digital I/O function, HV on MCLR must be used for programming)
#pragma config CPD = OFF        // Data EE Memory Code Protection bit (Data memory code protection off)
#pragma config CP = OFF         // Flash Program Memory Code Protection bit (Code protection off)

void main(void) 
{
    uint8_t stuff;
    //set each comparator for digital i/o on port a bits 0 to 3
    CMCONbits.CM0 = 1;
    CMCONbits.CM1 = 1;
    CMCONbits.CM2 = 1;
    
    //Port A set to all inputs.
    TRISA = 0xFF;
    
    //Port B set to outputs on all.
    TRISB = 0x00;
    
    //PORT B & A set to 0
    PORTB = 0;
    PORTA = 0;

    __delay_ms(1000);
    
    // 5 and 6 for bcf are bank select bits.  Clear them for bank 0.
    // STATUS 0 is the carry bit. check if the result of the add is a not a carry.
    // if its a not a carry lets store are work register to a general register at 0x20
    #asm
        bcf STATUS, 5
        bcf STATUS, 6
        test:
        movf  PORTA,w
        addlw 0xF0
        btfsc STATUS,0
        goto test
        movwf 0x20
    #endasm

    __delay_ms(1000);

    //get the data from general register 20, put it in are work register.
    //then move the work register to PORTB
    #asm
        movf 0x20,w
        movwf PORTB
    #endasm

    //you spin me right round like a record baby... FOREVER
    for(;;) {}
}

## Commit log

2022-04-30 expanded picerino to have 3 slots instead of 1. allowing multiple devices to be used.
    [PICerino.kicad_pcb, PICerino.sch]
2023-01-16 mit license update
    [PICerino.kicad_sch, PICerino.sch]
2024-10-10 start change over to multi-cart
    [PICerino.kicad_pcb, PICerino.kicad_sch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]
2024-10-26 added all updates to base repo
    [colecovision_multi_cart_15in1-B_Adhesive.gbr, colecovision_multi_cart_15in1-B_Courtyard.gbr, colecovision_multi_cart_15in1-B_Cu.gbr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]
2024-10-26 major addition of everything, first working makefile for all build sources.
    [bottom.stl, top.stl]
2024-10-27 add gerber files and wiki latex update
    [colecovision_multicart-B_Adhesive.gbr, colecovision_multicart-B_Courtyard.gbr, colecovision_multicart-B_Cu.gbr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]
2024-12-02 fixed solder mask cart edge
    [colecovision_multicart-B_Adhesive.gbr, colecovision_multicart-B_Courtyard.gbr, colecovision_multicart-B_Cu.gbr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]
